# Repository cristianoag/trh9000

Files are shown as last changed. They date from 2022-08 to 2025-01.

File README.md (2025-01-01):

# TRH9000
The Yamaha V9990 based open-source video card for the MSX

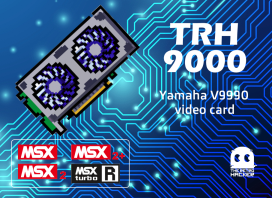
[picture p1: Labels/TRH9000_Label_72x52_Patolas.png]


## Introduction

If you ever spent just a few minutes on YouTube searching for MSX content, I bet you certainly found some footage covering the V9990. Well, not specifically the V9990 chip, but video cards based on it.

The first video card based on the unreleased, kind of obscure Yamaha V9990 VDP chip was the Graphics9000 (or GFX9000). The GFX9000 is (was) a graphics expansion device for MSX computers developed by Sunrise in 1994.

It was designed as an expansion cartridge for the MSX standard that can be installed in a slot on a computer that also connects to the computer’s video output and monitor. The device works as an additional independent video controller.

The device is based on the Yamaha V9990 video controller (VDP). The chip was designed specifically for use in computers of the alleged but not implemented (by the time of this writing) MSX3 standard. The V9990 is not backward compatible with the V99x8 chips, and thus cannot be used as the main video controller of standard MSX-compatible computers.

## The TRH9000

TRH9000 is an open-source implementation of the GFX9000, representing a community-driven effort to document everything necessary to build MSX cartridges that can run V9990 software.

| PCB Front | PCB Back |
| --- | --- |
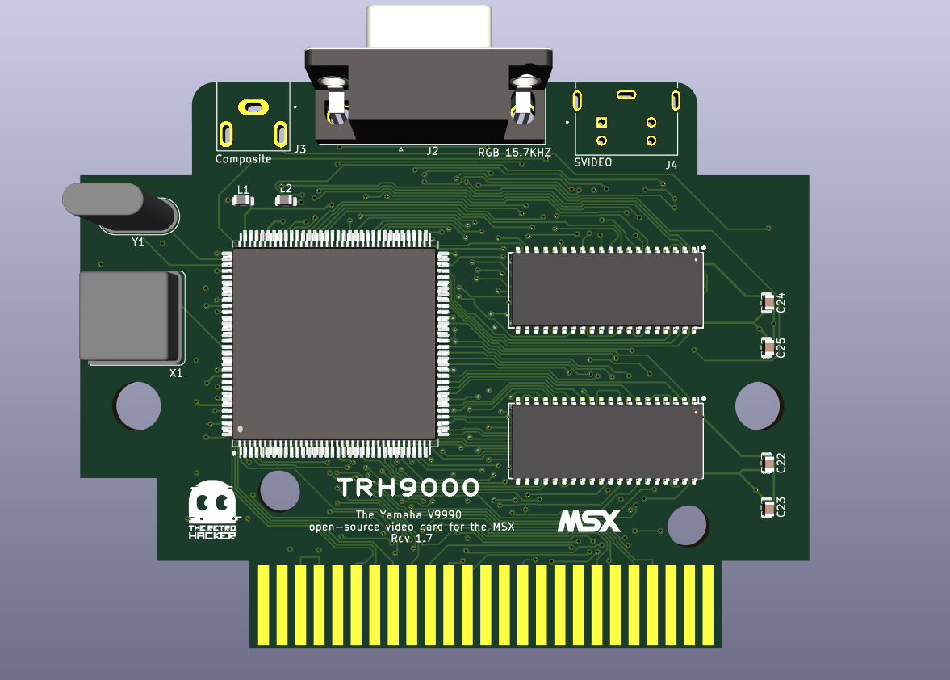
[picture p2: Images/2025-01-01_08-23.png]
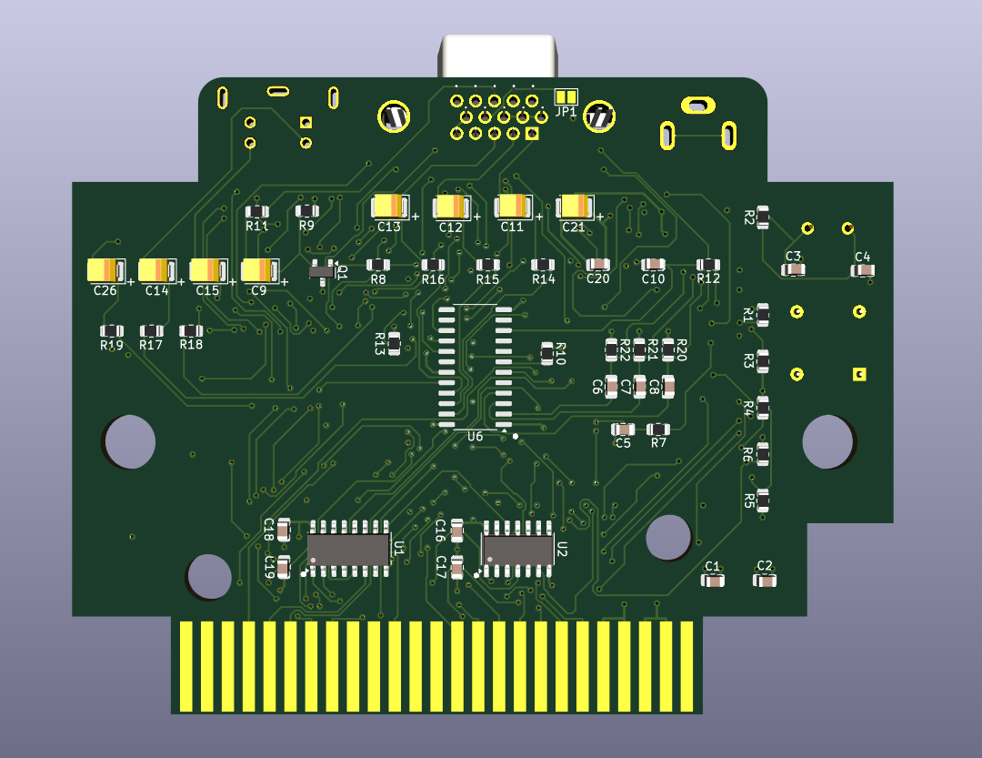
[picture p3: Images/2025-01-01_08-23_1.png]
|  |  |

The goal is to make those cards more accessible and improve the amount of software available for it. 

## Technical Information

The TRH9000 is a graphics expansion cartridge designed for MSX computers that was developed by a community of MSX enthusiasts as an open-source implementation of the GFX9000. 

### Selection Logic
For the TRH9000, the control logic is implemented by two ICs. According to the not exhaustive list of IO ports documented [here](https://www.msx.org/wiki/I/O_Ports_List). The IO ports used the by an GFX9000 compatible cartridge must be 60h~6Fh*. The 74LS138 IC on the board performs the selection of those IO ports and with the aid of the 74LS32 performs the activation of the appropriate signals on the V9990 chip.

> **Note:** Very important to use the 74LS138 and 74LS32 ICs. The 74HC138 and 74HC32 are not 100% compatible with the logic levels used by old MSX computers and if used, the cartridge may not work properly. 74HCT138 and 74HCT32 are also compatible with the old logic levels and can be used as a replacement.

### RAM chips

The KM428C256 RAM chip is the primary memory module used in the TRH9000. It is a CMOS 256K x 8 bit dual-port dynamic random-access memory (DRAM) chip that serves as the primary memory module in the cartridge. We use two memory chips, wired to the Yamaha V9990 VDP.

### Connectors

On its latest version, the TRH9000 features three types of video output connectors: a DB15 RGB/VGA connector, a RCA composite connector and a mini-DIN 4 SVideo connector. The DB15 connector is a standard video connector that supports VGA, and RGB, making it a versatile choice for connecting to various types of displays. The SVIDEO signal, on the other hand, is a video signal that carries the chrominance and luminance components of the video separately, resulting in a higher quality image than composite video that is output on the RCA connector. 

### Video Output

#### RGB 
The TRH9000 cartridge produces RGB signal with a horizontal frequency of 15.7KHz, which was the standard at the time of the V9990 chip's release. If you plan to connect the cartridge directly to your monitor using a VGA cable, it's important to ensure that your monitor supports synchronization at 15.7KHz.

You can see a list of modern monitors with support to 15.7KHz available at http://15khz.wikidot.com/

If you're not getting any image from the cartridge connector, it indicates that your monitor cannot sync at 15.7KHz. Typically, modern monitors can only sync at frequencies above 31KHz.

In such a scenario, you will require an adapter to upscale the frequency, making it compatible with your monitor. These adapters are commonly used for vintage video games and are readily available in various marketplaces. Here are a few options to consider:

||Description|Link|
|--|--|--|
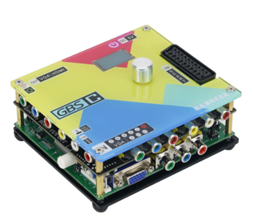
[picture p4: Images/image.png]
||TZT HamGeek GBSC Converter GBS Control Retro Video Game Signal Converter Gaming Accessory  |[Ali Express](https://s.click.aliexpress.com/e/_DcZRM6T)
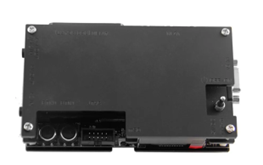
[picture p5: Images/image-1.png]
||OSSC HDMI-Compatible Converter Open Source Scan Adapter Kit with Game Cable for Retro Game Consoles  |[Ali Express](https://s.click.aliexpress.com/e/_DnNQGvv)
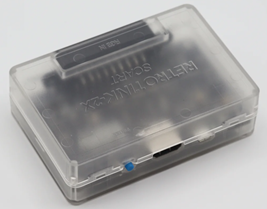
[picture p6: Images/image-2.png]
||Retrotink 2X Scart | https://www.retrotink.com/product-page/retrotink-2x-scart

If you decide to use the Retrotink you will need a VGA to SCART cable. That is easy to solder and you need to connect the signals in the following way:

|VGA||SCART|Signal|
|-|-|-|-|
|1|-->|15 |Red
|2|-->|11| Green
|3|--> |7 |Blue
|5|--> |21 |GND
|13|-->|20| Sync

By request of the community, a jumper was included on the latest PCB version to provide optionally 5V on the pin 9 of the VGA connector. This is useful for those who want to use build a SCART cable that depending on the monitor may require 5V in some pins. 

The jumper is located on the back of the PCB and is labeled as "JP1". The default position is open, so if you need to use it, you will need to close it with a solder blob.

Here is a diagram of the DH15 connector:

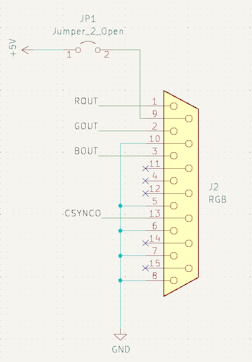
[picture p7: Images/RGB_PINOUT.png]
RGB pinout


#### S-Video and Composite

The TRH9000 cartridge provides support for both S-Video and Composite video outputs. These video signals are transmitted through respective connectors that are located on the upper edge of the cartridge PCB. 

## Bill of Materials

[TRH9000 Interactive BOM](https://htmlpreview.github.io/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)

|References|Value|Footprint|Qtd|Link|
|-|-|-|-|-|
|C1, C6, C7, C8, C17, C19, C20, C22, C24	|0.1uF	|C_0805_2012Metric	|9|[Ali Express](https://s.click.aliexpress.com/e/_DkAAT2J)
|C9, C11, C12, C13, C14, C15, C26|	220uF	|CP_EIA-3528-15_AVX-H|	7|[Ali Express](https://s.click.aliexpress.com/e/_DCrPttV)
|C3, C4	|27pF|	C_0805_2012Metric|	2|[Ali Express](https://s.click.aliexpress.com/e/_DkAAT2J)
|C5, C10|	47pF	|C_0805_2012Metric|	2|[Ali Express](https://s.click.aliexpress.com/e/_DkAAT2J)
|C16, C18|	1uF	|C_0805_2012Metric	|2|[Ali Express](https://s.click.aliexpress.com/e/_DkAAT2J)
|C23, C25|	10nF|	C_0805_2012Metric|	2|[Ali Express](https://s.click.aliexpress.com/e/_DkAAT2J)
|C2|	10uF|	C_0805_2012Metric	|1|[Ali Express](https://s.click.aliexpress.com/e/_DkAAT2J)
|C21|	47uF|	CP_EIA-3528-15_AVX-H|	1|[Ali Express](https://s.click.aliexpress.com/e/_DCrPttV)
|R1, R3, R4, R5, R6, R10|	4K7	|R_0805_2012Metric|	6|[Ali Express](https://s.click.aliexpress.com/e/_DEyTmBN)
|R14, R15, R16, R17, R18, R19|	75R	|R_0805_2012Metric|	6|[Ali Express](https://s.click.aliexpress.com/e/_DEyTmBN)
|R20,R21,R22|470R|R_0805_2012Metric|3|[Ali Express](https://s.click.aliexpress.com/e/_DEyTmBN)
|R7, R12|	2K2	|R_0805_2012Metric|	2|[Ali Express](https://s.click.aliexpress.com/e/_DEyTmBN)
|			R2	|10M	|R_0805_2012Metric|	1|[Ali Express](https://s.click.aliexpress.com/e/_DEyTmBN)
|			R8	|1K	|R_0805_2012Metric|	1|[Ali Express](https://s.click.aliexpress.com/e/_DEyTmBN)
|			R9	|100R	|R_0805_2012Metric|	1|[Ali Express](https://s.click.aliexpress.com/e/_DEyTmBN)
|			R11	|220R	|R_0805_2012Metric	|1|[Ali Express](https://s.click.aliexpress.com/e/_DEyTmBN)
|			R13	|3K3|	R_0805_2012Metric	|1|[Ali Express](https://s.click.aliexpress.com/e/_DEyTmBN)
|			L1, L2|	4.7uH|	L_0805_2012Metric	|2|[Ali Express](https://s.click.aliexpress.com/e/_Dern3vN)
|			U4, U5	|KM428C256	|SOJ-40_400mil|	2|[UT Source](https://www.utsource.net/itm/p/781989.html)
|			U1	|74HC138	|SO-16_3.9x9.9mm_P1.27mm	|1|[Ali Express](https://s.click.aliexpress.com/e/_De0MrAf)
|			U2	|74HC32	|SO-14_3.9x8.65mm_P1.27mm|	1|[Ali Express](https://s.click.aliexpress.com/e/_DlCjJDN)
|			U3|	V9990|	LQFP-128_28x28mm_P0.8mm	|1|[The Retro Hacker Store](https://theretrohacker.com/product/v9990-non-vga-video-controller-ic-qfp-128/)
|			U6	|CXA2075M	|SOP-24_7.5x15.4mm_P1.27mm|	1|[Ali Express](https://s.click.aliexpress.com/e/_DBjZMTN)
|			Y1	|21.47727Mhz	|Crystal_HC49-U_Vertical|	1|[Ali Express](https://s.click.aliexpress.com/e/_DDj3q9t)
|			X1	|14.31818MHz|	Oscillator_DIP-4|	1|[Ali Express](https://s.click.aliexpress.com/e/_DEBzKw3)
|			RV1, RV2, RV3	|500R	|Potentiometer_Bourns_3314G_Vertical	|3|[Ali Express](https://s.click.aliexpress.com/e/_DnebEdD)
|			Q1	|BC817	|SOT-23	|1|[Ali Express](https://s.click.aliexpress.com/e/_DBlTES3)
|			J4	|S-Video	|Mini DIN 4 Pin Connector | 1 | [Ali Express](https://s.click.aliexpress.com/e/_De7X4Ud)
|			J2	|RGB	|DSUB-15-HD_Female_Horizontal	|1|[Ali Express](https://s.click.aliexpress.com/e/_DntckRl)
| J3	|Composite	|RCA-2_Horizontal	|1|[Ali Express](https://s.click.aliexpress.com/e/_DBxnR6d)

## Community Contributions

There are a few folks activelly helping with the project and I would like to call them out here:

* Alexandre Souza
* Doomn00b
* Darlei Duarte
* lintweaker
* Luciano Sturaro
* MetalGear2
* sdsnatcher73
* sdsnatcher
* Thiago Valença
* Wagner Tavares

## License 

Open Hardware

This work is licensed under a [Creative Commons Attribution-NonCommercial-ShareAlike 4.0 International License](http://creativecommons.org/licenses/by-nc-sa/4.0/).

* If you remix, transform, or build upon the material, you must distribute your contributions under the same license as the original.
* You may not use the material for commercial purposes.
* You must give appropriate credit, provide a link to the license, and indicate if changes were made. You may do so in any reasonable manner, but not in any way that suggests the licensor endorses you or your use.

**ATTENTION**

This project was made for the retro community and not for commercial purposes. So only retro hardware forums and individual people can build this project.

THE SALE OF ANY PART OF THIS PROJECT WITHOUT EXPRESS AUTHORIZATION IS PROHIBITED!

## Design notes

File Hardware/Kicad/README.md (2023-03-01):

# TRH9000
The Yamaha V9990 based open-source video card for the MSX

## Kicad Project Files

* MSX_Breadboard_Large_V9990/ - This project involves a prototype cartridge designed to validate the main TRH9000 circuit. The board project is based on the work done by Alexey Wierzbowsky and has been adapted to include pads for memory chips, V9990, and two different video chips. We are currently testing the Sony RGB encoder (CXA2075M) and the TI Auto-Detecting SD/HD/PC Video Sync Separator (LMH1980) to generate the video signal.

* TRH9000.cxa2075/ - This is the main TRH9000 circuit and PCB project that utilizes the Sony CXA2075 RGB encoder. This board has been tested and is fully functional, delivering very good image quality.

* TRH9000.lmh1980/ - This is another version of the main TRH9000 circuit and PCB project that uses the Texas LMH1980 sync separator. While this board is functional, it doesn't follow the best practices when connecting to the RGB.

* TRH9000S/ - The TRH9000S is the latest version of the main TRH9000 circuit and PCB board project. This version features two connectors, including one DIN8 270 to receive input from the MSX computer and another DB15 as the RGB/VGA output. However, please note that this board also uses the LMH1980 and does not follow the best practices when connecting to the RGB. As a result, I recommend that you not use this board on your vintage hardware, as it is still under development and may cause harm to your computers.
* 
## License 

This work is licensed under the CERN OHL-S v2. You may redistribute and modify this project and its documentation under the terms of the CERN-OHL-S v2.

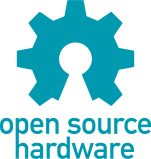
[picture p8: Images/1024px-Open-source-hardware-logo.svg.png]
Open Hardware


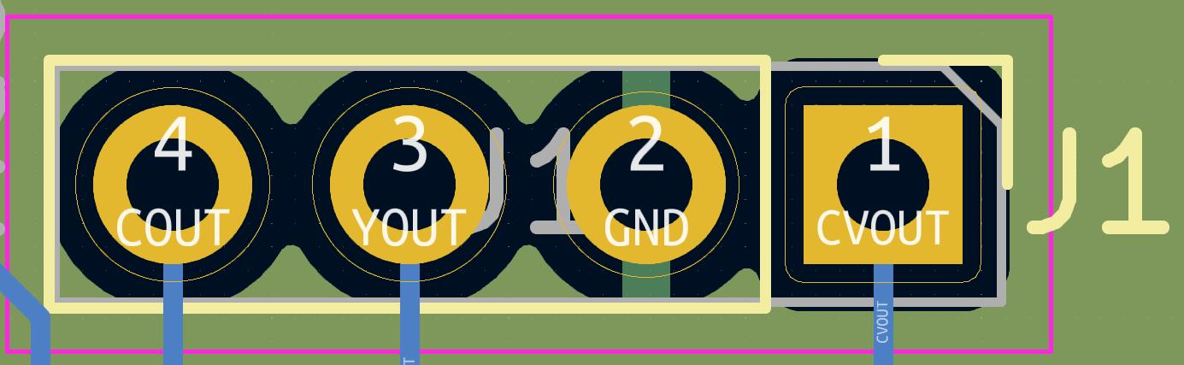
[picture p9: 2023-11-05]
Images/TRH9000_pinout.jpg

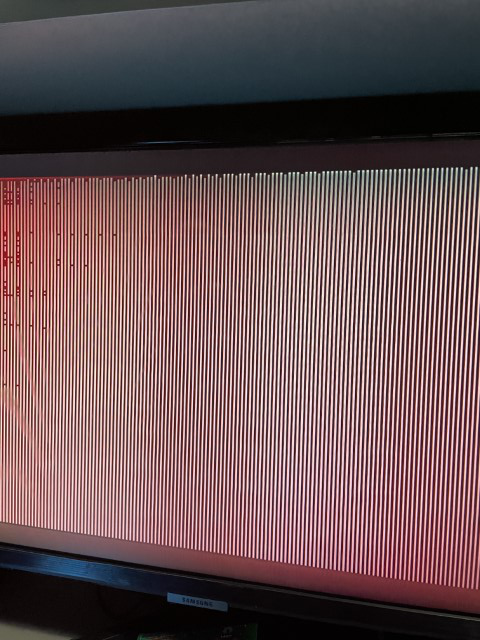
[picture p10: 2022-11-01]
Images/20221030_232553778_iOS_sm.jpg

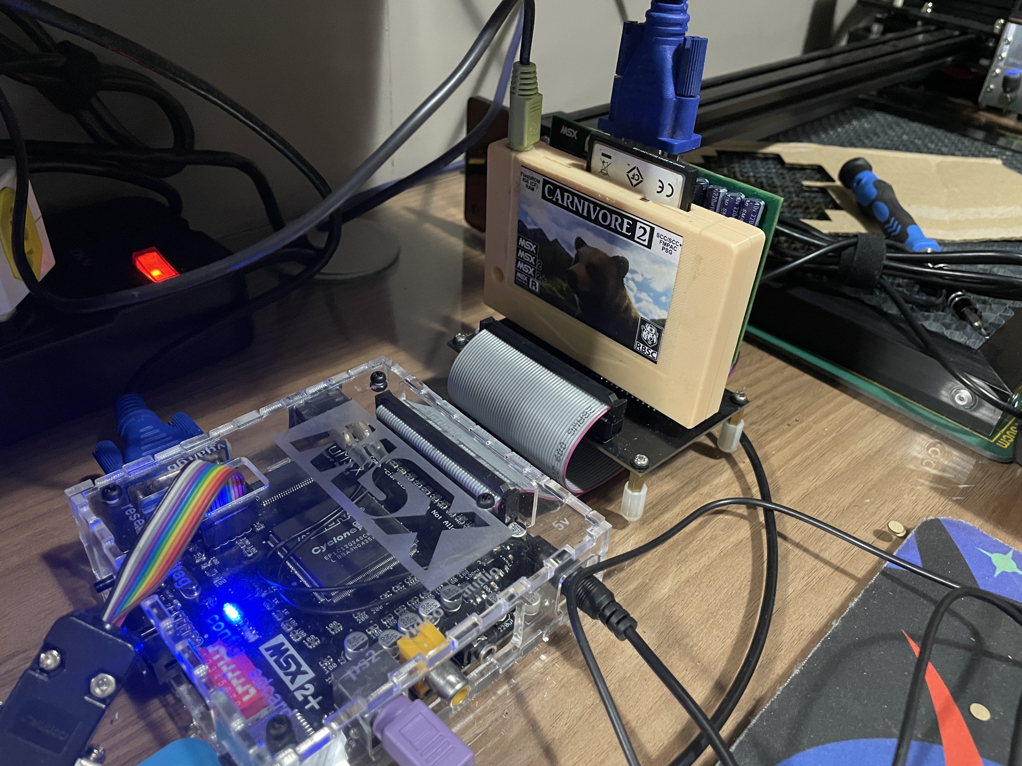
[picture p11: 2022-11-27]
Images/20221127_033815822_iOS.jpg

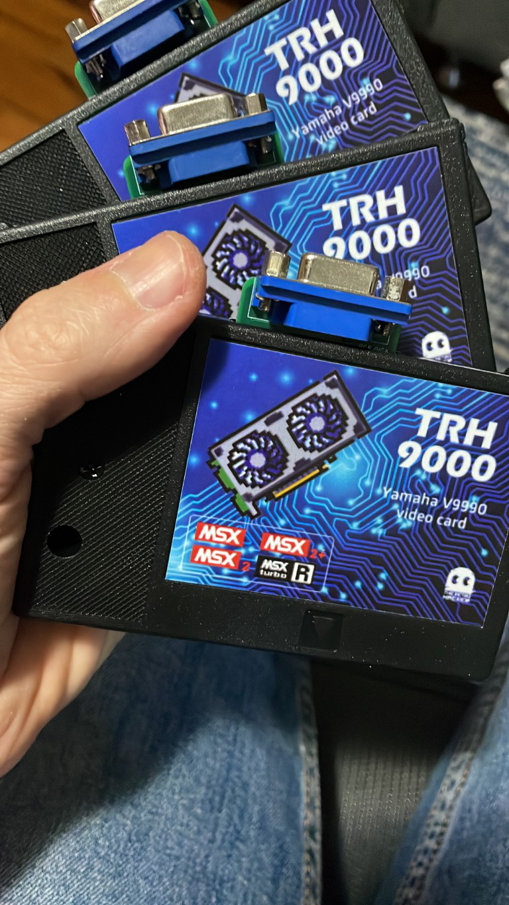
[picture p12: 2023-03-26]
Images/20230325_002200703_iOS.jpg

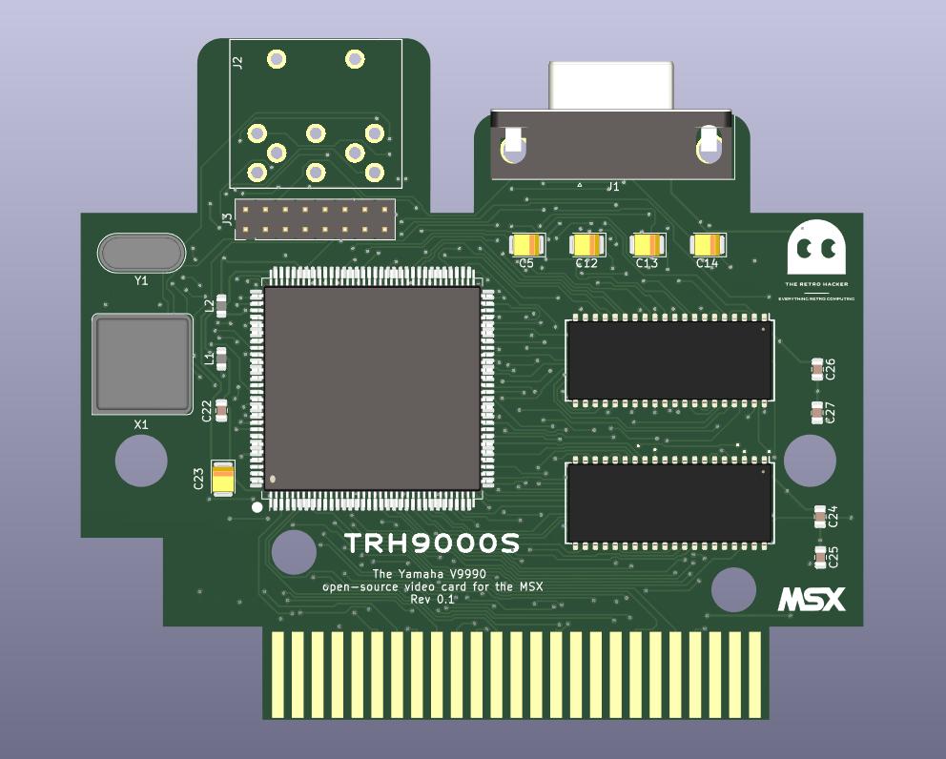
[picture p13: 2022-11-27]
Images/TRH9000S_0.jpg

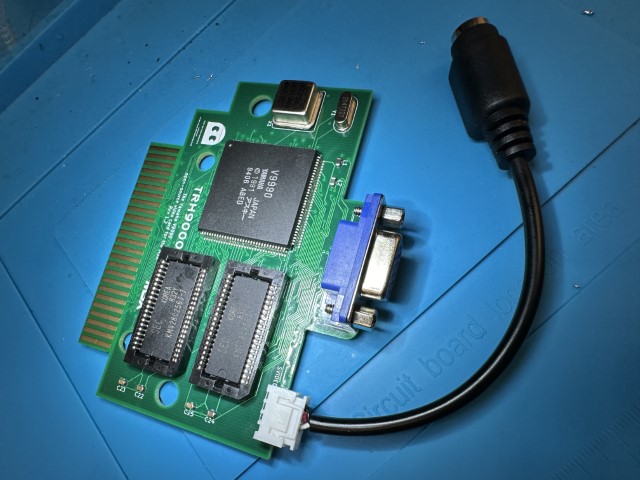
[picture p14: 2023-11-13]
Images/SVIDEO.jpg

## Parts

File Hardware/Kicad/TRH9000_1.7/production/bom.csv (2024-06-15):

Designator | Footprint | Quantity | Value | LCSC Part #
C1, C17, C19, C22, C24 | 0805 | 5 | 0.1uF
C10, C5 | 0805 | 2 | 47pF
C11, C12, C13, C14, C15, C26, C9 | CP_EIA-3528-15_AVX-H | 7 | 220uF
C16, C18 | 0805 | 2 | 1uF
C2 | 0805 | 1 | 10uF
C20, C6, C7, C8 | 0805 | 4 | 100nF
C21 | CP_EIA-3528-15_AVX-H | 1 | 47uF
C23, C25 | 0805 | 2 | 10nF
C3, C4 | 0805 | 2 | 27pF
J2 | DSUB-15-HD_Female_Horizontal_P2.29x1.98mm_EdgePinOffset3.03mm_Housed_MountingHolesOffset4.94mm | 1 | RGB
J3 | SWITCHCRAFT_PJRAN1X1U02AUX | 1 | Composite
J4 | CUI_MD-40SM | 1 | SVIDEO
JP1 | SolderJumper-2_P1.3mm_Open_Pad1.0x1.5mm | 1 | Jumper_2_Open
L1, L2 | 0805 | 2 | 4.7uH
Q1 | SOT-23 | 1 | BC817
R1, R10, R3, R4, R5, R6 | 0805 | 6 | 4K7
R11 | 0805 | 1 | 220R
R12, R7 | 0805 | 2 | 2K2
R13 | 0805 | 1 | 3K32 1%
R14, R15, R16, R17, R18, R19 | 0805 | 6 | 75R
R2 | 0805 | 1 | 10M
R20, R21, R22 | 0805 | 3 | 470R
R8 | 0805 | 1 | 1K
R9 | 0805 | 1 | 100R
U1 | SO-16_3.9x9.9mm_P1.27mm | 1 | 74HC138 | 74HC138
U2 | SO-14_3.9x8.65mm_P1.27mm | 1 | 74HC32 | 74HC32
U3 | LQFP-128_28x28mm_P0.8mm | 1 | V9990 | V9990
U4, U5 | SOJ-40_400mil | 2 | KM428C256
U6 | SO-24_5.3x15mm_P1.27mm | 1 | CXA2075M
X1 | Oscillator_DIP-8 | 1 | 14.31818MHz | CE3291-14.318180
Y1 | Crystal_HC49-U_Vertical | 1 | 21.47727Mhz

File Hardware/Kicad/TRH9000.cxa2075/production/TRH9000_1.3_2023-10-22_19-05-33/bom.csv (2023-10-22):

Designator | Footprint | Quantity | Value | LCSC Part #
C1, C17, C19, C22, C24 | 0805 | 5 | 0.1uF
C10, C5 | 0805 | 2 | 47pF
C11, C12, C13, C14, C15, C9 | CP_EIA-3528-15_AVX-H | 6 | 220uF
C16, C18 | 0805 | 2 | 1uF
C2 | 0805 | 1 | 10uF
C20, C6, C7, C8 | 0805 | 4 | 100nF
C21 | CP_EIA-3528-15_AVX-H | 1 | 47uF
C23, C25 | 0805 | 2 | 10nF
C3, C4 | 0805 | 2 | 27pF
J1 | PinHeader_1x04_P2.54mm_Vertical | 1 | S-Video
J2 | DSUB-15-HD_Female_Horizontal_P2.29x1.98mm_EdgePinOffset3.03mm_Housed_MountingHolesOffset4.94mm | 1 | RGB
JP1 | SolderJumper-2_P1.3mm_Open_Pad1.0x1.5mm | 1 | Jumper_2_Open
L1, L2 | 0805 | 2 | 4.7uH
Q1 | SOT-23 | 1 | BC817
R1, R10, R3, R4, R5, R6 | 0805 | 6 | 4K7
R11 | 0805 | 1 | 220R
R12, R7 | 0805 | 2 | 2K2
R13 | 0805 | 1 | 3K3
R14, R15, R16, R17, R18 | 0805 | 5 | 75R
R2 | 0805 | 1 | 10M
R8 | 0805 | 1 | 1K
R9 | 0805 | 1 | 100R
RV1, RV2, RV3 | Potentiometer_Bourns_3314G_Vertical | 3 | 500R
U1 | SO-16_3.9x9.9mm_P1.27mm | 1 | 74HC138 | 74HC138
U2 | SO-14_3.9x8.65mm_P1.27mm | 1 | 74HC32 | 74HC32
U3 | LQFP-128_28x28mm_P0.8mm | 1 | V9990 | V9990
U4, U5 | SOJ-40_400mil | 2 | KM428C256
U6 | SOP-24_7.5x15.4mm_P1.27mm | 1 | CXA2075M
X1 | Oscillator_DIP-8 | 1 | 14.31818MHz | CE3291-14.318180
Y1 | Crystal_HC49-U_Vertical | 1 | 21.47727Mhz

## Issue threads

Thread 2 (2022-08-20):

[request] Add the Superimposer

sdsnatcher, 2022-08-20:
Except for the Video9000, none of the later V9990 cartridges had the superimposer to allow the V9990 image to be placed over the V99x8 image.

Please add this feature, because:

1) It allows for much richer games for low cost, using the V9958 as a colorful 3rd background plane
2) It makes it easier to use, since it won't be necessary to switch between two unrelated video outputs anymore

cristianoag, 2022-08-21:
Totally agree with this. However depending on the size of the circuitry we need to do superimpose we may need to extend the size of the cartridge (taller). That will require a custom cartridge box.

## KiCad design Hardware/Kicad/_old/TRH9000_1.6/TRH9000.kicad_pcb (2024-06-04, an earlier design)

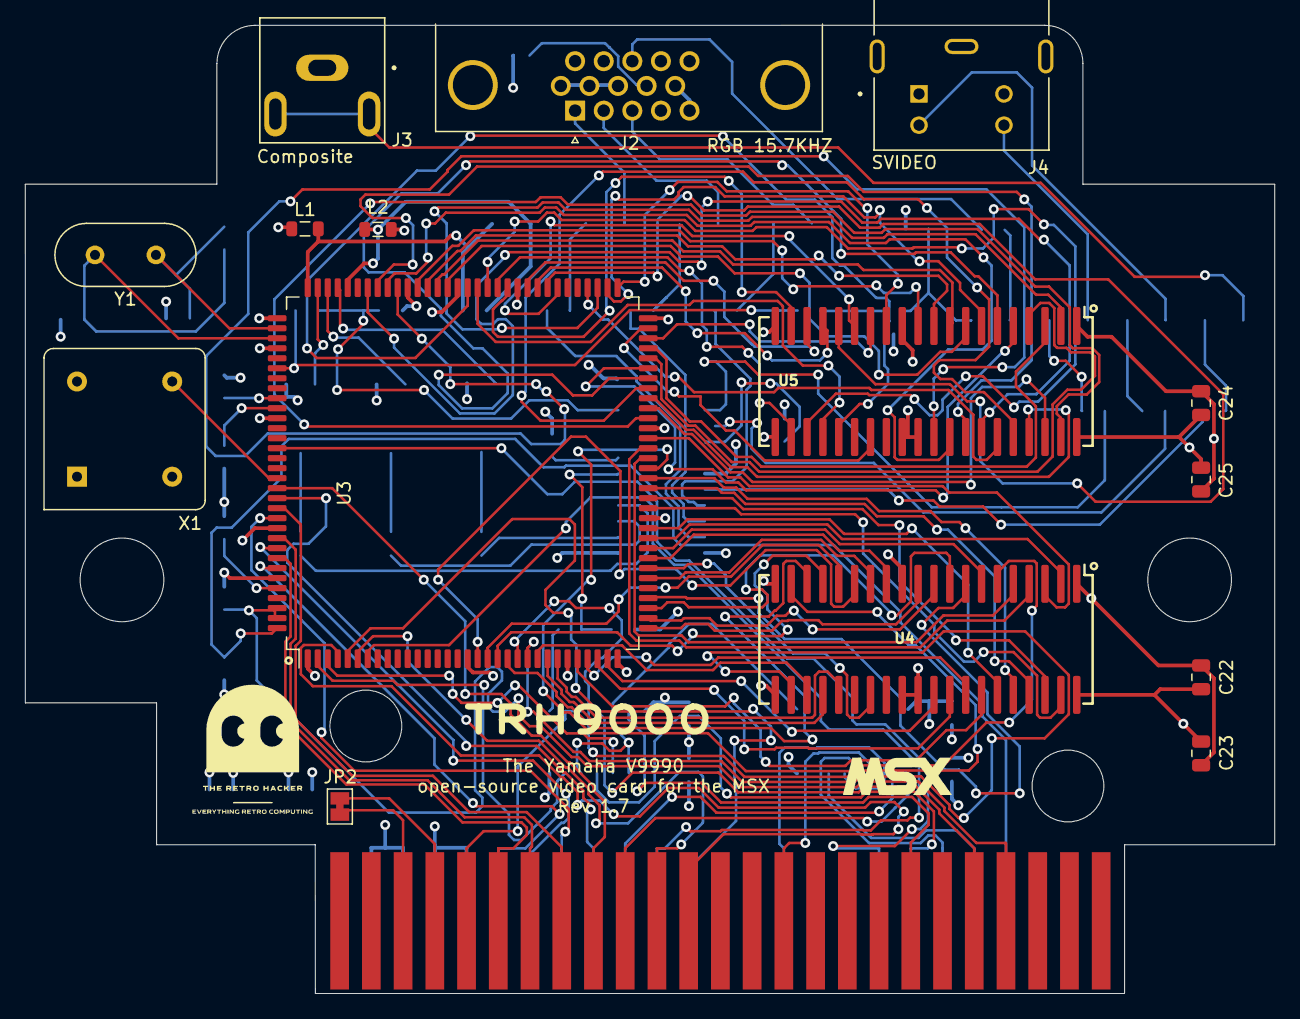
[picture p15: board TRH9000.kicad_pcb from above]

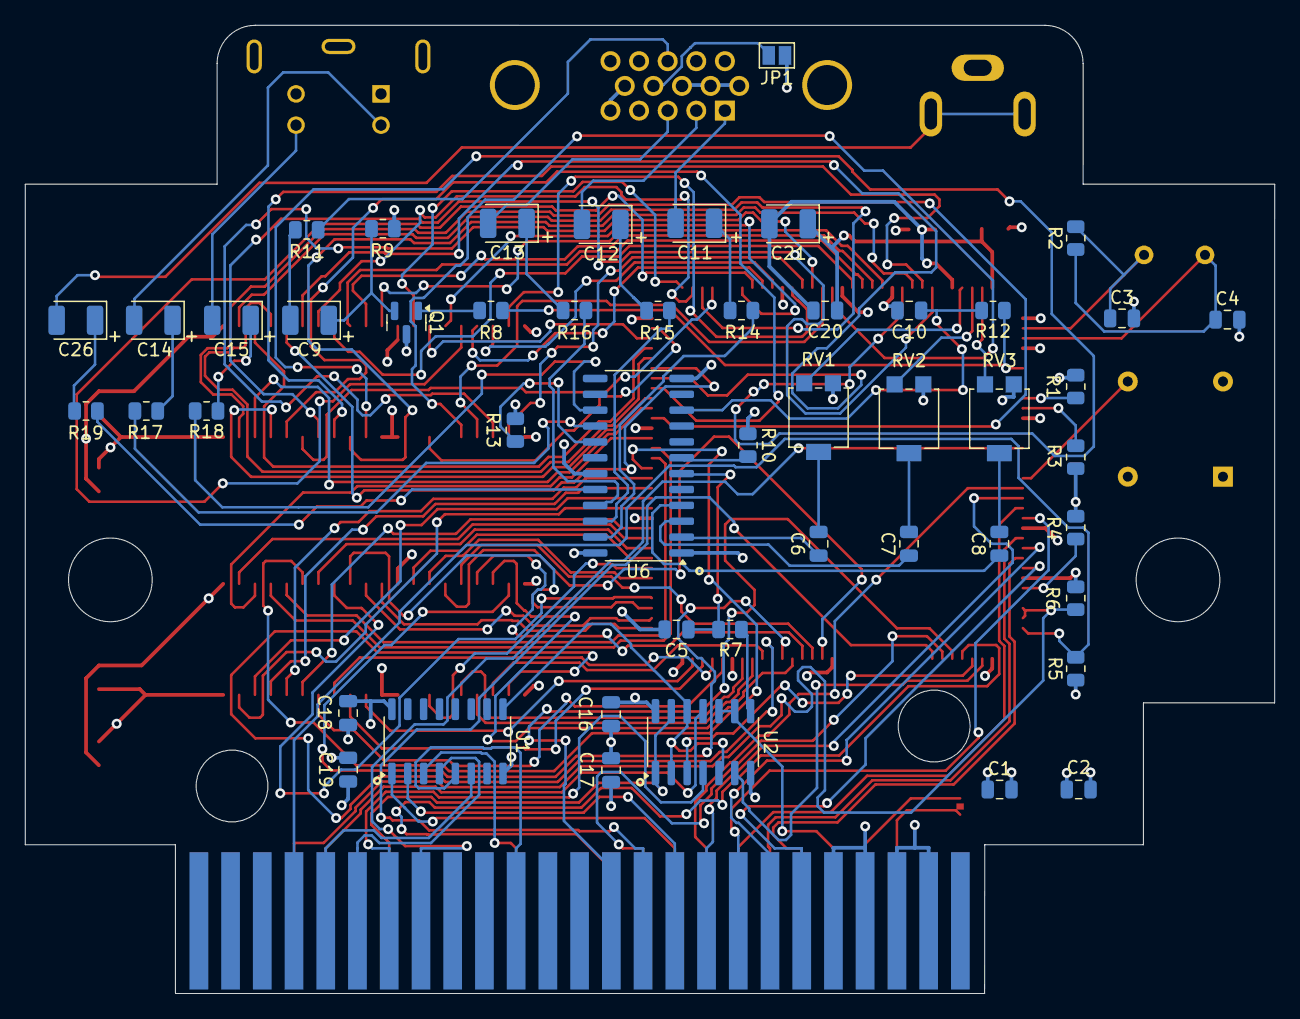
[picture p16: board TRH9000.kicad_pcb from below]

Board: 4 copper layers, 100.0 x 77.5 mm, 67 parts (49 on the bottom side), 140 nets.

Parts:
BUS1: MSX_SLOT_EDGE-CON; msx_cartridge
C1, C17, C19, C22, C24: 0.1uF; C_0805_2012Metric
C2: 10uF; C_0805_2012Metric
C3, C4: 27pF; C_0805_2012Metric
C5, C10: 47pF; C_0805_2012Metric
C6, C7, C8, C20: 100nF; C_0805_2012Metric
C9, C11, C12, C13, C14, C15, C26: 220uF; CP_EIA-3528-15_AVX-H
C16, C18: 1uF; C_0805_2012Metric
C21: 47uF; CP_EIA-3528-15_AVX-H
C23, C25: 10nF; C_0805_2012Metric
J2: RGB; DSUB-15-HD_Female_Horizontal_P2.29x1.98mm_EdgePinOffset3.03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
J3: Composite; SWITCHCRAFT_PJRAN1X1U02AUX
J4: SVIDEO; CUI_MD-40SM
JP1: Jumper_2_Open; SolderJumper-2_P1.3mm_Open_Pad1.0x1.5mm
JP2: Jumper_2_Bridged; SolderJumper-2_P1.3mm_Bridged_Pad1.0x1.5mm
L1, L2: 4.7uH; L_0805_2012Metric
MSX1: LOGO
Q1: BC817; SOT-23
R1, R3, R4, R5, R6, R10: 4K7; R_0805_2012Metric
R2: 10M; R_0805_2012Metric
R7, R12: 2K2; R_0805_2012Metric
R8: 1K; R_0805_2012Metric
R9: 100R; R_0805_2012Metric
R11: 220R; R_0805_2012Metric
R13: 3K3; R_0805_2012Metric
R14, R15, R16, R17, R18, R19: 75R; R_0805_2012Metric
RV1, RV2, RV3: 500R; Potentiometer_Bourns_3314G_Vertical
TRH1: LOGO; TRH
U1: 74HC138; SO-16_3.9x9.9mm_P1.27mm
U2: 74HC32; SO-14_3.9x8.65mm_P1.27mm
U3: V9990; LQFP-128_28x28mm_P0.8mm
U4, U5: KM428C256; SOJ-40_400mil
U6: CXA2075M; SO-24_5.3x15mm_P1.27mm
X1: 14.31818MHz; Oscillator_DIP-8
Y1: 21.47727Mhz; Crystal_HC49-U_Vertical

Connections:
+5V: BUS1.45 (+5V), BUS1.47 (+5V), C1.1, C2.1, C16.1, C17.1, C18.1, C19.1, C22.1, C23.2, C24.1, C25.2, JP1.1 (A), L1.1, Q1.3 (C), R1.1, R3.2, R4.1, R5.1, R6.1, R10.1, R13.1, U1.16 (VCC), U2.14 (VCC), U3.27 (VDD), U3.53 (VDD), U3.81 (VDD), U3.97 (VDD), U3.123 (VDD), U4.1 (VCC), U4.20 (VCC), U5.1 (VCC), U5.20 (VCC), U6.12 (VCC), U6.19 (VCC), X1.1 (EN), X1.8 (Vcc)
+5VA: C20.1, C21.1, L1.2, U3.96 (VDDA)
/A0: BUS1.28 (A0), U3.4 (MODE0)
/A1: BUS1.27 (A1), U3.5 (MODE1)
/A2: BUS1.30 (A2), U3.6 (MODE2)
/A3: BUS1.29 (A3), U3.7 (MODE3)
/A4: BUS1.32 (A4), U1.1 (A0)
/A5: BUS1.31 (A5), U1.2 (A1)
/A6: BUS1.22 (A6), U1.3 (A2)
/A7: BUS1.21 (A7), U1.5 (~G2B)
/D0: BUS1.34 (D0), U3.114 (CD0)
/D1: BUS1.33 (D1), U3.115 (CD1)
/D2: BUS1.36 (D2~), U3.116 (CD2)
/D3: BUS1.35 (D3), U3.117 (CD3)
/D4: BUS1.38 (D4), U3.119 (CD4)
/D5: BUS1.37 (D5), U3.120 (CD5)
/D6: BUS1.40 (D6), U3.121 (CD6)
/D7: BUS1.39 (D7), U3.122 (CD7)
/SW1: BUS1.44 (SW1), JP2.2 (B)
/SW2: BUS1.46 (SW2), JP2.1 (A)
/SYS_CLK: BUS1.42 (CLOCK), U2.9 (3A), U2.10 (3B)
/VDP/B: RV3.3, U3.95 (B/D1/CB1)
/VDP/G: RV2.3, U3.94 (G/D2/CB2)
/VDP/HRESET: R1.2, U3.105 (~HRESET/CB4)
/VDP/MCKIN: U3.113 (MCKIN), X1.5 (OUT)
/VDP/R: RV1.3, U3.93 (R/D3/CB3)
/VDP/V0A0: U3.26 (V0_A0/KA0), U4.25 (A0)
/VDP/V0A1: U3.25 (V0_A1/KA1), U4.24 (A1)
/VDP/V0A2: U3.24 (V0_A2/KA2), U4.23 (A2)
/VDP/V0A3: U3.23 (V0_A3/KA3), U4.22 (A3)
/VDP/V0A4: U3.22 (V0_A4/KA4), U4.19 (A4)
/VDP/V0A5: U3.21 (V0_A5/KA5), U4.18 (A5)
/VDP/V0A6: U3.20 (V0_A6/KA6), U4.17 (A6)
/VDP/V0A7: U3.19 (V0_A7/KA7), U4.16 (A7)
/VDP/V0A8: U3.18 (V0_A8/KA8), U4.15 (A8)
/VDP/V0D0: U3.36 (V0_D0/KD0), U4.8 (W0/DQ0)
/VDP/V0D1: U3.35 (V0_D1/KD1), U4.9 (W1/DQ1)
/VDP/V0D2: U3.34 (V0_D2/KD2), U4.10 (W2/DQ2)
/VDP/V0D3: U3.33 (V0_D3/KD3), U4.11 (W3/DQ3)
/VDP/V0D4: U3.31 (V0_D4/KD4), U4.31 (W4/DQ4)
/VDP/V0D5: U3.30 (V0_D5/KD5), U4.32 (W5/DQ5)
/VDP/V0D6: U3.29 (V0_D6/KD6), U4.33 (W6/DQ6)
/VDP/V0D7: U3.28 (V0_D7/KD7), U4.34 (W7/DQ7)
/VDP/V0S0: U3.52 (V0_S0), U4.3 (SDQ0)
/VDP/V0S1: U3.51 (V0_S1), U4.4 (SDQ1)
/VDP/V0S2: U3.50 (V0_S2), U4.5 (SDQ2)
/VDP/V0S3: U3.49 (V0_S3), U4.6 (SDQ3)
/VDP/V0S4: U3.48 (V0_S4), U4.36 (SDQ4)
/VDP/V0S5: U3.47 (V0_S5), U4.37 (SDQ5)
/VDP/V0S6: U3.46 (V0_S6), U4.38 (SDQ6)
/VDP/V0S7: U3.45 (V0_S7), U4.39 (SDQ7)
/VDP/V1A0: U3.80 (V1_A0), U5.25 (A0)
/VDP/V1A1: U3.79 (V1_A1), U5.24 (A1)
/VDP/V1A2: U3.78 (V1_A2), U5.23 (A2)
/VDP/V1A3: U3.77 (V1_A3), U5.22 (A3)
/VDP/V1A4: U3.76 (V1_A4), U5.19 (A4)
/VDP/V1A5: U3.74 (V1_A5), U5.18 (A5)
/VDP/V1A6: U3.73 (V1_A6), U5.17 (A6)
/VDP/V1A7: U3.72 (V1_A7), U5.16 (A7)
/VDP/V1A8: U3.71 (V1_A8), U5.15 (A8)
/VDP/V1D0: U3.82 (V1_D0), U5.8 (W0/DQ0)
/VDP/V1D1: U3.83 (V1_D1), U5.9 (W1/DQ1)
/VDP/V1D2: U3.84 (V1_D2), U5.10 (W2/DQ2)
/VDP/V1D3: U3.85 (V1_D3), U5.11 (W3/DQ3)
/VDP/V1D4: U3.87 (V1_D4), U5.31 (W4/DQ4)
/VDP/V1D5: U3.88 (V1_D5), U5.32 (W5/DQ5)
/VDP/V1D6: U3.89 (V1_D6), U5.33 (W6/DQ6)
/VDP/V1D7: U3.90 (V1_D7), U5.34 (W7/DQ7)
/VDP/V1S0: U3.61 (V1_S0), U5.3 (SDQ0)
/VDP/V1S1: U3.60 (V1_S1), U5.4 (SDQ1)
/VDP/V1S2: U3.59 (V1_S2), U5.5 (SDQ2)
/VDP/V1S3: U3.58 (V1_S3), U5.6 (SDQ3)
/VDP/V1S4: U3.57 (V1_S4), U5.36 (SDQ4)
/VDP/V1S5: U3.56 (V1_S5), U5.37 (SDQ5)
/VDP/V1S6: U3.55 (V1_S6), U5.38 (SDQ6)
/VDP/V1S7: U3.54 (V1_S7), U5.39 (SDQ7)
/VDP/VMREQ: R4.2, U3.124 (~VMREQ)
/VDP/VRESET: R3.1, U3.106 (~VRESET/CB5)
/VDP/X1: C3.1, R2.2, U3.98 (XTAL1), Y1.1
/VDP/X2: C4.1, R2.1, U3.99 (XTAL2), Y1.2
/VDP/~CSYNC: R8.2, R12.1, U3.102 (~CSYNC/FLM)
/VDP/~V0_CAS: U3.39 (~V0_CAS), U4.27 (~CAS)
/VDP/~V0_RAS: U3.38 (~V0_RAS), U4.14 (~RAS)
/VDP/~V0_SC: U3.42 (~V0_SC), U4.2 (SC)
/VDP/~V0_TR: U3.41 (~V0_TR/OE), U4.7 (~DT/~OE)
/VDP/~V0_WE: U3.40 (~V0_WE), U4.13 (~WB/~WE)
/VDP/~V1_CAS: U3.63 (~V1_CAS), U5.27 (~CAS)
/VDP/~V1_RAS: U3.62 (~V1_RAS), U5.14 (~RAS)
/VDP/~V1_SC: U3.67 (V1_SC), U5.2 (SC)
/VDP/~V1_SOE: U3.68 (~V1_SOE), U5.35 (~SE)
/VDP/~V1_TR: U3.66 (~V1_TR/OE), U5.7 (~DT/~OE)
/VDP/~V1_WE: U3.65 (~V1_WE), U5.13 (~WB/~WE)
/VDP/~VDPR: U2.3 (1Y), U3.3 (~CSR)
/VDP/~VDPW: U2.6 (2Y), U3.2 (~CSW)
/VDP/~VO_SOE: U3.43 (~V0_SOE), U4.35 (~SE)
/VIDEO/BOUT: C13.2, J2.3
/VIDEO/COUT: C15.2, J4.4
/VIDEO/CSYNCO: J2.13, R11.1
/VIDEO/CVOUT: C26.2, J3.2, J3.3
/VIDEO/GOUT: C12.2, J2.2
/VIDEO/ROUT: C11.2, J2.1
/VIDEO/SCIN: R7.2, U2.8 (3Y)
/VIDEO/YOUT: C14.2, J4.3
/~BUSDIR: BUS1.10 (~BUSDIR), U2.11 (4Y)
/~INT: BUS1.8 (~INT), R6.2, U3.126 (~INT0), U3.127 (~INT1)
/~IORQ: BUS1.11 (~IORQ), U1.4 (~G2A)
/~M1: BUS1.9 (~M1), U1.6 (G1)
/~RD: BUS1.14 (~RD), U2.1 (1A), U2.13 (4B)
/~RESET: BUS1.15 (~RESET), U3.110 (~RESET)
/~WAIT: BUS1.7 (~WAIT), R5.2, U3.128 (~WAIT)
/~WR: BUS1.13 (~WR), U2.4 (2A)
GND: BUS1.41 (GND), BUS1.43 (GND), C1.2, C2.2, C3.2, C4.2, C5.2, C10.2, C16.2, C17.2, C18.2, C19.2, C22.2, C23.1, C24.2, C25.1, J2.5, J2.6, J2.7, J2.8, J2.10, J3.1, J4.1, J4.2, J4.S1 (SHIELD), J4.S2 (SHIELD), J4.S3 (SHIELD), L2.1, R9.2, RV1.1, RV2.1, RV3.1, U1.8 (GND), U2.7 (GND), U3.1 (VSS), U3.17 (VSS), U3.32 (VSS), U3.44 (VSS), U3.64 (VSS), U3.75 (VSS), U3.86 (VSS), U3.100 (VSS), U3.107 (VSS), U3.118 (VSS), U4.12 (VSS), U4.21 (VSS), U4.29 (DSF), U4.30 (VSS), U4.40 (VSS), U5.12 (VSS), U5.21 (VSS), U5.29 (DSF), U5.30 (VSS), U5.40 (VSS), U6.1 (GND), U6.24 (GND), X1.4 (GND)
GNDA: C20.2, C21.2, L2.2, U3.92 (VSSA)
unnamed: C6.2, RV1.2
unnamed: C7.2, RV2.2
unnamed: C8.2, RV3.2
unnamed: C9.2, R11.2
unnamed: C11.1, R14.1
unnamed: C12.1, R15.1
unnamed: C13.1, R16.1
unnamed: C14.1, R17.1
unnamed: C15.1, R18.1
unnamed: C26.1, R19.1
unnamed: J2.9, JP1.2 (B)
unnamed: Q1.1 (B), R8.1
unnamed: C9.1, Q1.2 (E), R9.1
unnamed: U1.9 (~Y6), U2.2 (1B), U2.5 (2B), U2.12 (4A)
unnamed: C8.1, U6.4 (BIN)
unnamed: R16.2, U6.21 (BOUT)
unnamed: R18.2, U6.15 (COUT)
unnamed: R19.2, U6.20 (CVOUT)
unnamed: C7.1, U6.3 (GIN)
unnamed: R15.2, U6.22 (GOUT)
unnamed: R10.2, U6.7 (NPIN)
unnamed: C6.1, U6.2 (RIN)
unnamed: R14.2, U6.23 (ROUT)
unnamed: C5.1, R7.1, U6.6 (SCIN)
unnamed: C10.1, R12.2, U6.10 (SYNCIN)
unnamed: R17.2, U6.16 (YOUT)
unnamed: R13.2, U6.17 (YTRAP)

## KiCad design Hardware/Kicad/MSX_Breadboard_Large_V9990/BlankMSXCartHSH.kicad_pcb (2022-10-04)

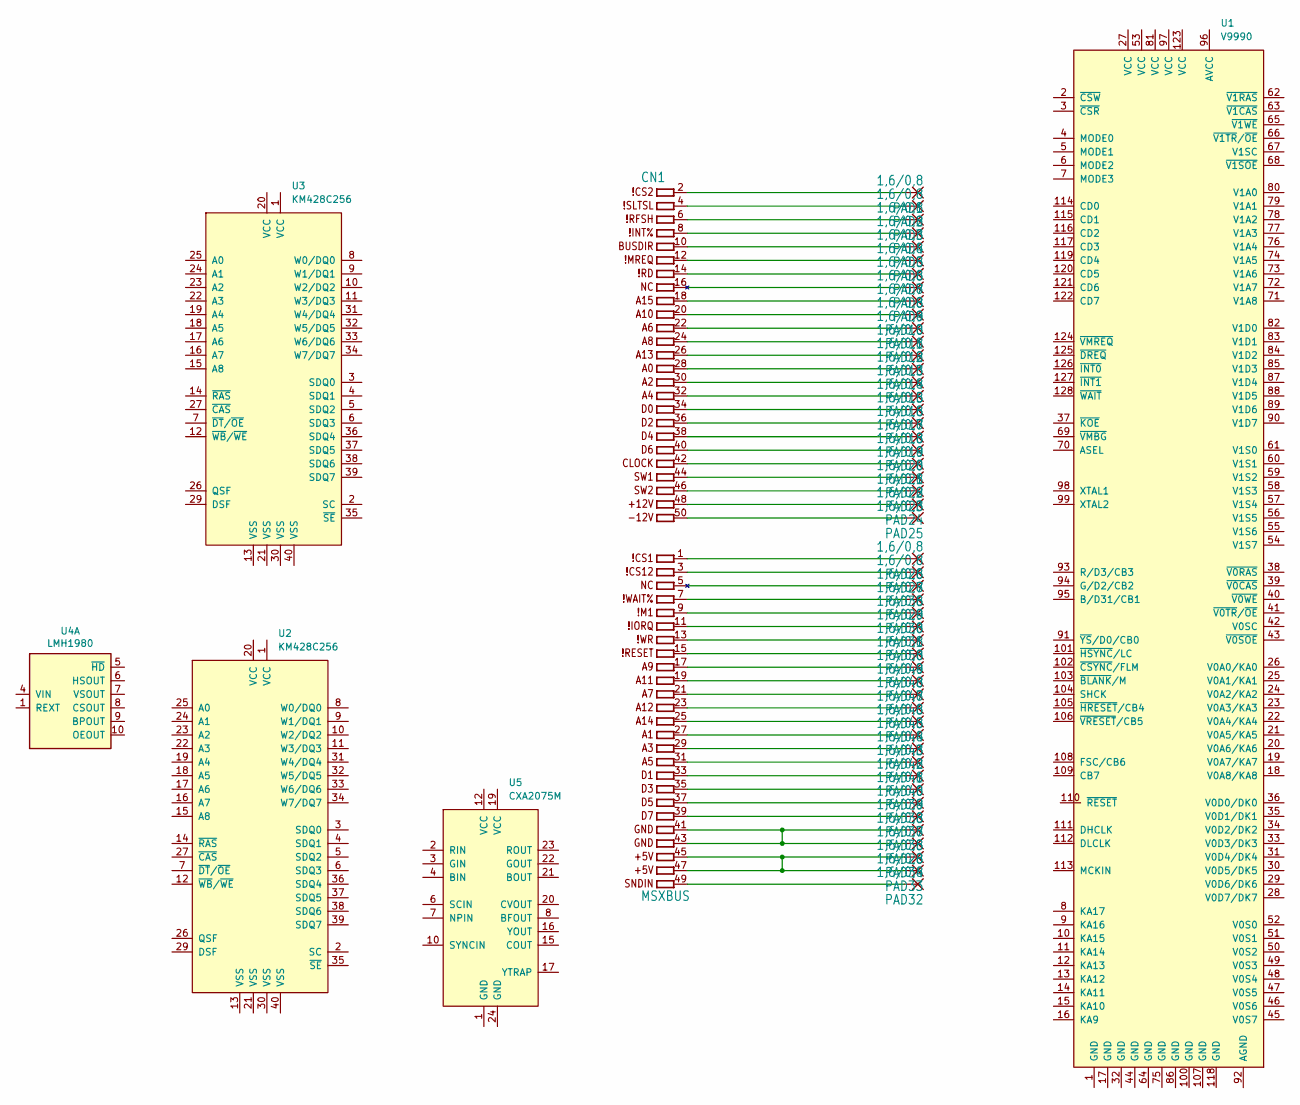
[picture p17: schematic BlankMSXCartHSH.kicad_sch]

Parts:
CN1: MSXBUS; MSXBUS_EDGECONN
PAD1, PAD2, PAD3, PAD4, PAD5, PAD6, PAD7, PAD8, PAD9, PAD10, PAD11, PAD12, PAD13, PAD14, PAD15, PAD16, PAD17, PAD18, PAD19, PAD20, PAD21, PAD22, PAD23, PAD24, PAD25, PAD26, PAD27, PAD28, PAD29, PAD30, PAD31, PAD32, PAD33, PAD34, PAD35, PAD36, PAD37, PAD38, PAD39, PAD40, PAD41, PAD42, PAD43, PAD44, PAD45, PAD46, PAD47, PAD48, PAD49, PAD50: 1,6/0,8; 1,6_0,8
U1: V9990; QFP-128_28x28_Pitch0.8mm
U2, U3: KM428C256; SOJ-40_400mil
U4: LMH1980; VSSOP-10_3x3mm_P0.5mm; MPN LMH1980MM/NOPBCT
U5: CXA2075M; SOP-24_7.5x15.4mm_P1.27mm

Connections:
+5V: CN1.45 (45.+5V), CN1.47 (47.+5V), PAD33.1, PAD34.1
GND: CN1.41 (41.GND), CN1.43 (43.GND), PAD28.1, PAD35.1
unnamed: CN1.2 (2.~CS2), PAD1.1
unnamed: CN1.4 (4.~SLTSL), PAD2.1
unnamed: CN1.6 (6.~RFSH), PAD3.1
unnamed: CN1.8 (8.~INT%), PAD4.1
unnamed: CN1.10 (10.BUSDIR), PAD5.1
unnamed: CN1.12 (12.~MREQ), PAD6.1
unnamed: CN1.14 (14.~RD), PAD7.1
unnamed: CN1.16 (16.NC), PAD8.1
unnamed: CN1.18 (18.A15), PAD9.1
unnamed: CN1.20 (20.A10), PAD10.1
unnamed: CN1.22 (22.A6), PAD11.1
unnamed: CN1.24 (24.A8), PAD12.1
unnamed: CN1.26 (26.A13), PAD13.1
unnamed: CN1.28 (28.A0), PAD14.1
unnamed: CN1.30 (30.A2), PAD15.1
unnamed: CN1.32 (32.A4), PAD16.1
unnamed: CN1.34 (34.D0), PAD17.1
unnamed: CN1.36 (36.D2), PAD18.1
unnamed: CN1.38 (38.D4), PAD19.1
unnamed: CN1.40 (40.D6), PAD20.1
unnamed: CN1.42 (42.CLOCK), PAD21.1
unnamed: CN1.44 (44.SW1), PAD22.1
unnamed: CN1.46 (46.SW2), PAD23.1
unnamed: CN1.48 (48.+12V), PAD24.1
unnamed: CN1.50 (50.-12V), PAD25.1
unnamed: CN1.1 (1.~CS1), PAD26.1
unnamed: CN1.3 (3.~CS12), PAD27.1
unnamed: CN1.5 (5.NC), PAD36.1
unnamed: CN1.7 (7.~WAIT%), PAD29.1
unnamed: CN1.9 (9.~M1), PAD30.1
unnamed: CN1.11 (11.~IORQ), PAD31.1
unnamed: CN1.49 (49.SNDIN), PAD32.1
unnamed: CN1.39 (39.D7), PAD37.1
unnamed: CN1.37 (37.D5), PAD38.1
unnamed: CN1.35 (35.D3), PAD39.1
unnamed: CN1.33 (33.D1), PAD40.1
unnamed: CN1.31 (31.A5), PAD41.1
unnamed: CN1.29 (29.A3), PAD42.1
unnamed: CN1.27 (27.A1), PAD43.1
unnamed: CN1.25 (25.A14), PAD44.1
unnamed: CN1.23 (23.A12), PAD45.1
unnamed: CN1.21 (21.A7), PAD46.1
unnamed: CN1.19 (19.A11), PAD47.1
unnamed: CN1.17 (17.A9), PAD48.1
unnamed: CN1.15 (15.~RESET), PAD49.1
unnamed: CN1.13 (13.~WR), PAD50.1

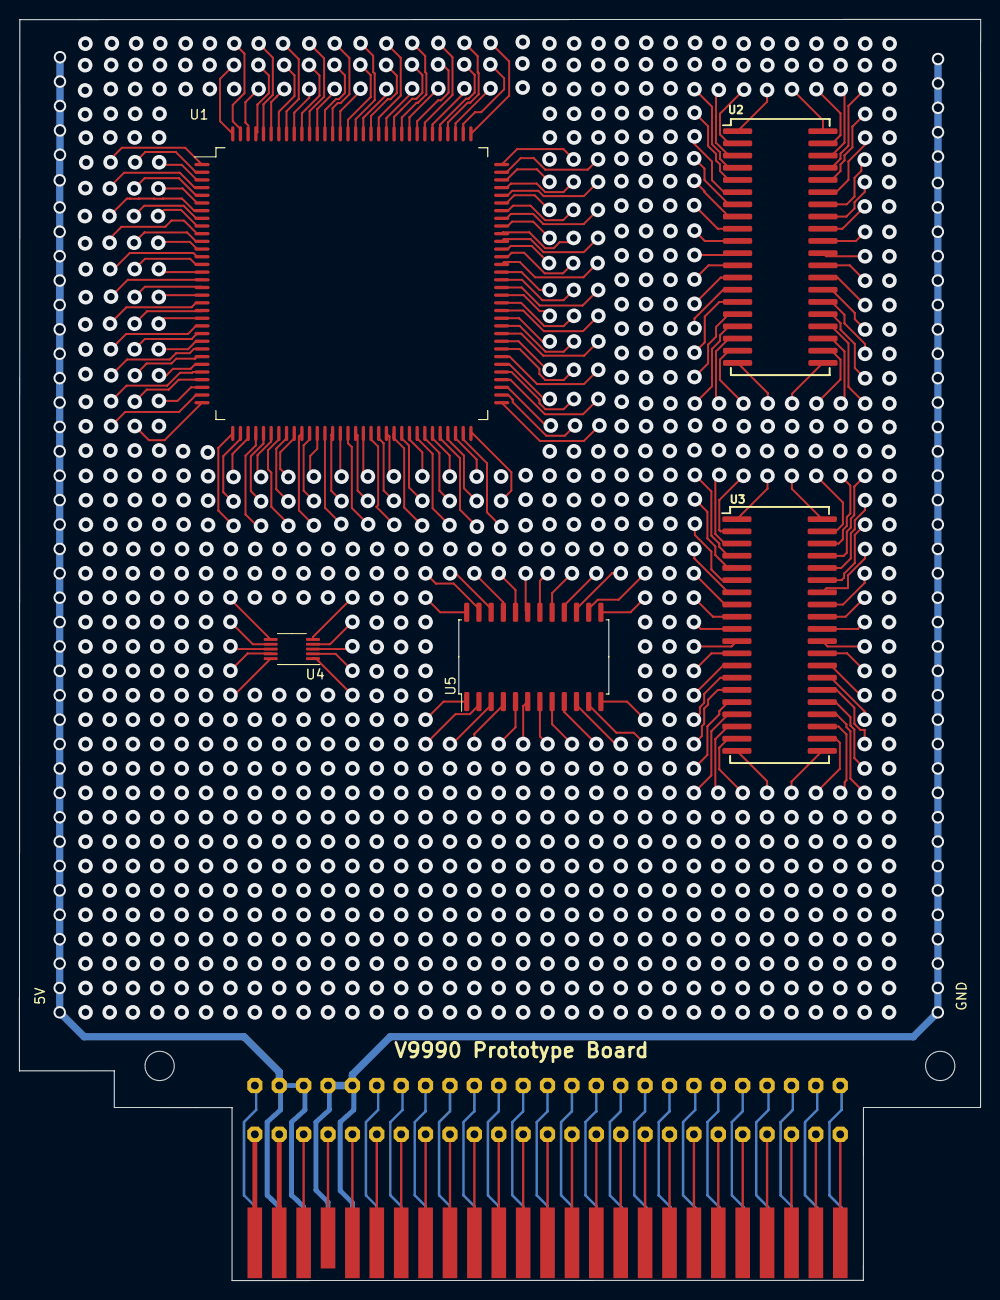
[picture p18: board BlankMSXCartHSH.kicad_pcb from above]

Board: 2 copper layers, 100.1 x 131.3 mm, 58 parts (0 on the bottom side), 48 nets.

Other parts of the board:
@HOLE0, @HOLE1: (no value)

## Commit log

2022-08-03 Revision 0 upload
    [TRH9000.kicad_pcb, TRH9000.kicad_sch, TRH9000_VDP.kicad_sch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]
2022-08-03 Footprint for the V9990
    [TRH9000.kicad_sch, TRH9000_VDP.kicad_sch, TRH9000_VIDEO.kicad_sch]
2022-08-03 Trimpots for the RGB coming from V9990
    [TRH9000.kicad_sch, TRH9000_VDP.kicad_sch, TRH9000_VIDEO.kicad_sch]
2022-08-04 REV0 - Footprint review
2022-08-04 Footprint adjusts
    [TRH9000.kicad_sch, TRH9000_VIDEO.kicad_sch]
2022-08-09 Initial component placement on the PCB.
    [TRH9000.kicad_pcb, TRH9000.kicad_sch, TRH9000_VDP.kicad_sch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]
2022-08-11 Routing 1. First 3d view of the current PCB.
    [TRH9000.kicad_pcb, TRH9000.kicad_sch, TRH9000_VDP.kicad_sch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]
2022-08-11 Changed Git-ignore to standard Kicad-format, added a changelog, started adding navigation-bookmarks to the datasheets.
    [Changelog.xlsx]
2022-08-15 Many changes, among them, replacing the Composite out with SCART-rgb.
    [Changelog.xlsx, Power_v9990.kicad_sch, TRH9000.kicad_pcb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]
2022-08-21 Multiple updates. Routing. Almost finished routing for the VDP. Moved back the footprint for the 14mhz oscillator to THT as it is easier to find outside US/Europe and I have a bunch laying around her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
    [Changelog.xlsx, Power_v9990.kicad_sch, TRH9000.kicad_pcb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]
2022-08-21 PCB image
2022-08-21 Routing, readme, etc
    [Changelog.xlsx, Power_v9990.kicad_sch, TRH9000.kicad_pcb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]
2022-08-21 MSX logo
    [TRH9000.kicad_pcb]
2022-08-22 Small correction on the front silkscreen
    [TRH9000.kicad_pcb]
2022-09-10 Prototype board. Fixes to the main project. Readme updates.
    [BlankMSXCartHSH-B_Cu.gbr, BlankMSXCartHSH-B_Mask.gbr, BlankMSXCartHSH-B_Paste.gbr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]
2022-09-21 Updates during tests with prototype
    [Power_v9990.kicad_sch, TRH9000.kicad_pcb, TRH9000.kicad_sch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]
2022-10-04 Multiple changes. Check the dev log.
    [Changelog.xlsx, Power_v9990.kicad_sch, TRH9000.kicad_pcb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]
2022-10-04 Small fix to the prototype MSX_Breadboard_Large_V9990 board
    [BlankMSXCartHSH.kicad_pcb]
2022-11-01 Multiple changes.
    [Power_v9990.kicad_sch, TRH9000.kicad_pcb, TRH9000.kicad_sch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]
2022-11-01 Minor adjustments
    [TRH9000.kicad_pcb]
2022-11-27 Board Images
2022-12-25 Moving caps to avoid conflict with sockets, uploading image with issue when superimposing
    [TRH9000.kicad_pcb, TRH9000.kicad_sch, TRH9000_VIDEO.kicad_sch]
2022-12-26 board review to use the CXA2075 instead of the LMH1980
    [Power_v9990.kicad_sch, TRH9000.kicad_pcb, TRH9000.kicad_sch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]
2022-12-26 changes on the readmes
    [TRH9000.kicad_pcb]
2023-02-28 small fix on the YTRAP to use internal for NTSC.
    [Power_v9990.kicad_sch, TRH9000.kicad_pcb, TRH9000.kicad_sch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]
2023-03-01 new gerber files and BOM
    [TRH9000.kicad_pcb, bom.csv, designators.csv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]
2023-03-24 board fabrication
2023-04-19 small fix on the B silkscreen
    [TRH9000.kicad_pcb]
2023-07-11 new gerber.zip
    [bom.csv]
2023-07-16 Small fix on the silk
    [TRH9000.kicad_pcb]
2023-09-24 Info on the Video Signal, links for the BOM, Availability of the V9990 on the store.
2023-10-22 Fix on VRAM wiring
    [Power_v9990.kicad_sch, TRH9000.kicad_pcb, TRH9000.kicad_sch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]
2023-10-22 Jumper to provide 5V to SCART cables
    [TRH9000.kicad_pcb, TRH9000_VIDEO.kicad_sch]
2023-10-22 Fabrication artifacts v1.3
    [bom.csv, designators.csv, positions.csv]
2023-10-22 Note on the readme file about the 5V jumper.
2023-10-22 Interactive bom
2023-11-05 Exposing composite, footprint and silk corrections
    [Power_v9990.kicad_sch, TRH9000.kicad_pcb, TRH9000.kicad_sch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]
2023-11-05 Instructions to build S-Video and Composite cables
2023-11-05 BOM adjustments
2023-11-05 Images for the README, mention to the XHB connector.
2023-11-13 Including the RGB pinout
    [TRH9000.kicad_pcb]
2023-11-13 S-Video cable instructions
2023-12-31 SW1-SW2 jumper. v1.41
    [TRH9000.kicad_pcb, TRH9000.kicad_sch]
2024-02-22 Updates to have Svideo and Composite exposed via appropriate connectors
    [TRH9000.kicad_pcb, TRH9000_VIDEO.kicad_sch, bom.csv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]
2024-03-19 Fix on pins 12 and 13 of the VRAM
    [Power_v9990.kicad_sch, TRH9000.kicad_pcb, TRH9000.kicad_sch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]
2024-06-04 kicad 8 migration. minor positioning for the connectors
    [Power_v9990.kicad_sch, TRH9000.kicad_pcb, TRH9000.kicad_sch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]
2024-06-15 Fix for B&W when turbo is enabled is specific computers.
    [Power_v9990.kicad_sch, TRH9000.kicad_pcb, TRH9000.kicad_sch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]
2024-06-15 v1.7 BOM on Readme
2025-01-01 Content organization. README.MD update.
    [Power_v9990.kicad_sch, TRH9000.kicad_pcb, TRH9000.kicad_sch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]

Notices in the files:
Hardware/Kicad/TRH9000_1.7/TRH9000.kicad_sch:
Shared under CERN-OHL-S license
